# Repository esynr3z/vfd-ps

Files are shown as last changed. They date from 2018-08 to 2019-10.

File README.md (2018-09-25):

# Power supply for VFD

## Features

Main parts of the VFD power supply: inverting buck-boost converter on TPS54360 (supposed to use with ICs like PT6311 and etc) and filament driver on LM4871.

Inverting converter:

* Input voltage: 5V
* Output negative voltage: -15V to -30V
* Output current: 250mA @ 5V in

Filament driver:

* Input voltage: 5V
* Output voltage: 5 to 0 (dummy resistors to regulate)
* Output power: 2W @ 5V in

## Board

Schematic and pcb layout created in KiCad 6 Nightly Build (compatible with KiCad 5).

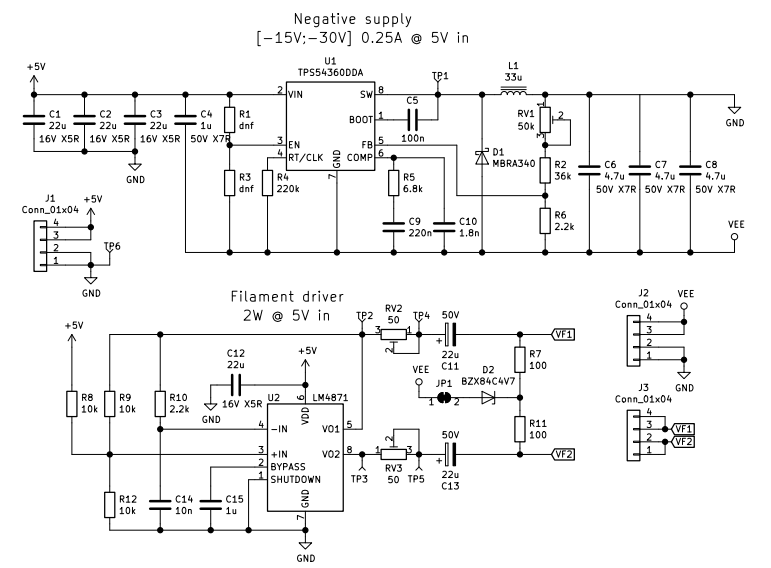
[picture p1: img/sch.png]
schematic

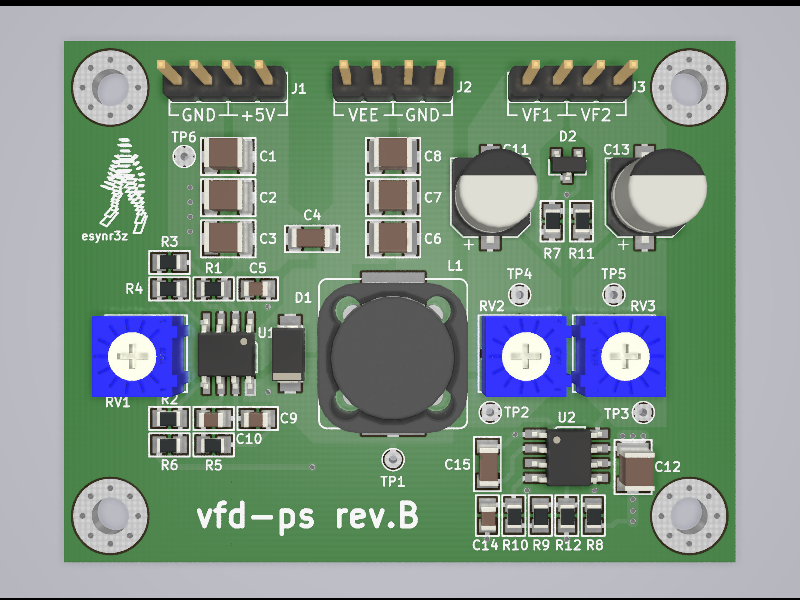
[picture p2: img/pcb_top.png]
pcb top

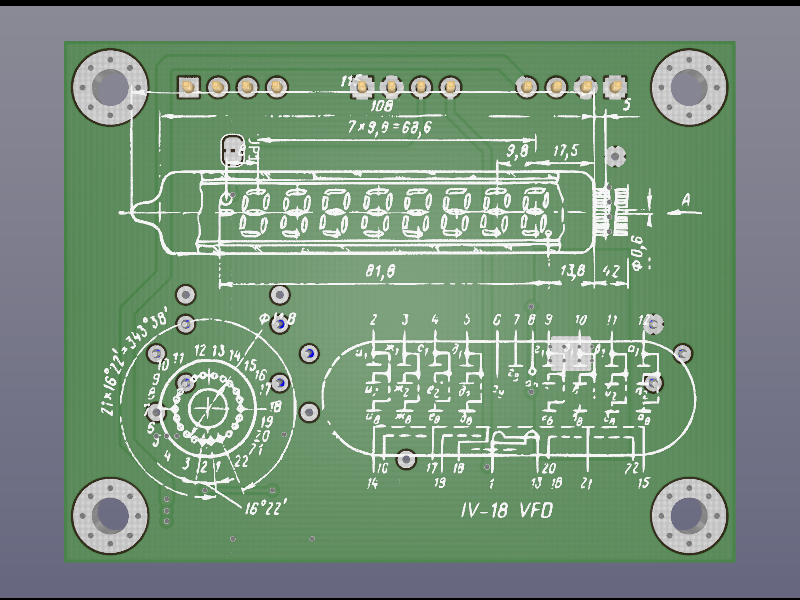
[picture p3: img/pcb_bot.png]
pcb bottom


## Notes

* ```misc``` folder contains some calculation and simulation sheets for several IC to get negative voltages

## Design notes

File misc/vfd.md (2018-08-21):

# VFD summary

Main specifications on some VFDs.

* **V_ag** - anodes and grids voltage
* **V_f** - filament voltage
* **I_at** - total current trough all anodes
* **I_g** - grid current
* **I_f** - filament current

| VFD | V_ag, V | I_at, mA | I_g, mA | V_f, V | I_f, mA |
|---:|---:|---:|---:|---:|---:|
| IV-3 | 20 | 0.3 | 3 | 0.8 | 50 |
| IV-3А | 20 | 0.3 | 3 | 0.8 | 30 |
| IV-4 | 25 | 0.45 | 6 | 2.6 | 50 |
| IV-6 | 25 | 0.6 | 10 | 1.0 | 50 |
| IV-8 | 20 | 0.8 | 3 | 0.8 | 50 |
| IV-11 | 25 | 3.5 | 12 | 1.5 | 100 |
| IV-12 | 25 | 3.5 | 12 | 1.5 | 100 |
| IV-17 | 25 | 2.7 | 6.5 | 2.5 | 47 |
| IV-18 | 50 | 45 | 10 | 5 | 85 |
| IV-21 | 27 | 0.7 | 7.0 | 1.0 | 100 |
| IV-22 | 27 | 12 | 0.02 | 2.4 | 35 |
|  IVL1-7/5 | 27 | 12 | 2.5 | 5 | 120 |
|  IVL2-7/5 | 24 | 27 | 3 | 2.4 | 58 |
|  IVC-4/7L | 27 | 70 | 10 | 2.4 | 100 |

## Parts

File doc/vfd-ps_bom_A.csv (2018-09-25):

Component | Description | Part | References | Value | Footprint | Quantity Per PCB | Datasheet | Rating
1 |  | Device_C | C10 | 1.8n | C_0805 | 1 | ~
2 |  | Device_C | C5 | 100n | C_0805 | 1 | ~
3 |  | Device_C | C14 | 10n | C_0805 | 1 | ~
4 |  | Device_C | C4 C15 | 1u | C_1206 | 2 | ~ | 50V X7R
5 |  | Device_C | C9 | 220n | C_0805 | 1 | ~
6 |  | Device_C | C1 C2 C3 C12 | 22u | C_1210 | 4 | ~ | 16V X5R
7 |  | Device_CP | C11 C13 | 22u | CP_Elec_6.3x7.7 | 2 | ~ | 50V
8 |  | Device_C | C6 C7 C8 | 4.7u | C_1210 | 3 | ~ | 50V X7R
9 |  | esynr3z_DiodeZener_BZX84C4V7 | D2 | BZX84C4V7 | SOT-23 | 1 | https://www.onsemi.com/pub/Collateral/BZX84C2V4LT1-D.PDF
10 |  | esynr3z_DiodeSchottky_MBRA340 | D1 | MBRA340 | SMA | 1 | https://www.onsemi.com/pub/Collateral/MBRA340T3-D.PDF
11 |  | Connector_Generic_Conn_01x04 | J1 J2 J3 | Conn_01x04 | PinHeader_1x04_P2.54mm_Vertical | 3 | ~
12 |  | Device_L_Core_Iron | L1 | 33u | Sumida_CDRH127 | 1 | ~
13 |  | Device_R | R7 R11 | 100 | R_0805 | 2 | ~
14 |  | Device_R | R8 R9 R12 | 10k | R_0805 | 3 | ~
15 |  | Device_R | R2 | 16k | R_0805 | 1 | ~
16 |  | Device_R | R6 | 1k | R_0805 | 1 | ~
17 |  | Device_R | R10 | 2.2k | R_0805 | 1 | ~
18 |  | Device_R | R4 | 220k | R_0805 | 1 | ~
19 |  | Device_R | R5 | 6.8k | R_0805 | 1 | ~
20 |  | Device_R_POT_TRIM | RV1 | 20k | Bourns_3362P | 1 | ~
21 |  | Device_R_POT_TRIM | RV2 RV3 | 50 | Bourns_3362P | 2 | ~
22 |  | esynr3z_AmplifierAudio_LM4871 | U2 | LM4871 | VSSOP-8_3.0x3.0mm_P0.65mm | 1 | http://www.ti.com/lit/ds/symlink/lm4871.pdf
23 |  | esynr3z_RegulatorSwitching_TPS54360DDA | U1 | TPS54360DDA | TI_SO-PowerPAD-8_ThermalVias | 1 | www.ti.com/lit/ds/symlink/tps54360.pdf
Component Groups: | 24
Component Count: | 38
Fitted Components: | 36
Number of PCBs: | 1
Total components: | 36
Schematic Version: | A
Schematic Date:
BoM Date: | Tue 25 Sep 2018 20:55:03 MSK
Schematic Source: | /home/esynr3z/MyRepos/vfd-ps/vfd-ps.sch
KiCad Version: | Eeschema 6.0.0-rc1-unknown-r13783-618182dc

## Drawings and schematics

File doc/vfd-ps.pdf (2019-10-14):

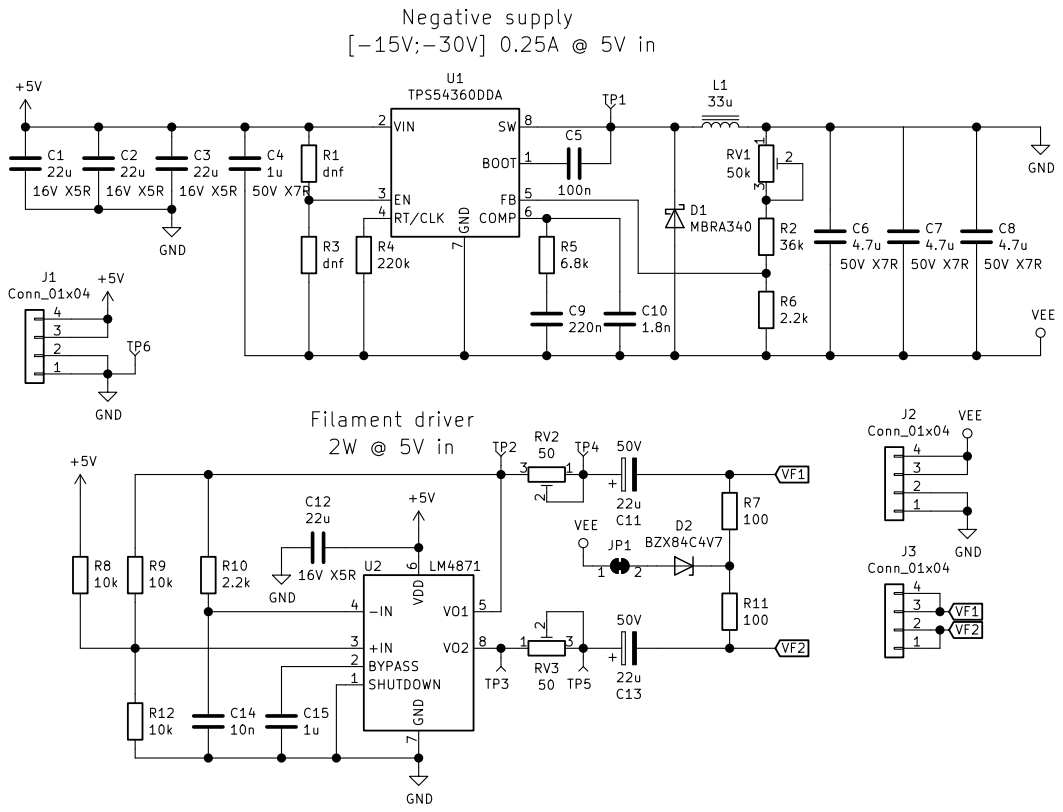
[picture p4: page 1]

File: vfd-ps.sch Sheet: /
Id: 1/1 Title: VFD power supply and filament driver

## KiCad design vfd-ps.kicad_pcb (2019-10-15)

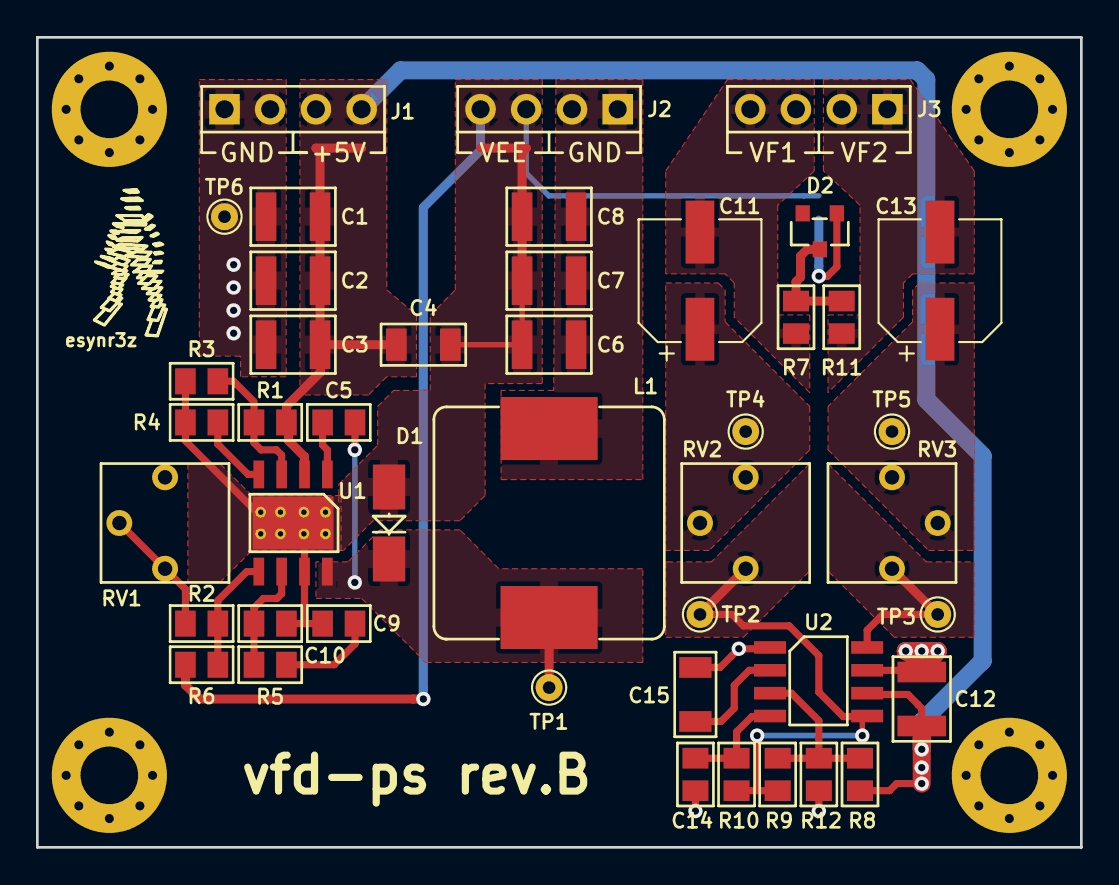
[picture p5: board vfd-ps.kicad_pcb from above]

Board: 2 copper layers, 58.0 x 45.0 mm, 45 parts (1 on the bottom side), 22 nets.

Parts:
C1, C2, C3, C12: 22u; C_1210
C4, C15: 1u; C_1206
C5: 100n; C_0805
C6, C7, C8: 4.7u; C_1210
C9: 220n; C_0805
C10: 1.8n; C_0805
C11, C13: 22u; CP_Elec_6.3x7.7
C14: 10n; C_0805
D1: MBRA340; SMA
D2: BZX84C4V7; SOT-23
J1, J2, J3: Conn_01x04; PinHeader_1x04_P2.54mm_Vertical
JP1: SolderJumper_2_Bridged; SolderJumper-2_P1.3mm_Bridged2Bar_RoundedPad1.0x1.5mm
L1: 33u; Sumida_CDRH127
R1, R3: dnf; R_0805
R2: 36k; R_0805
R4: 220k; R_0805
R5: 6.8k; R_0805
R6, R10: 2.2k; R_0805
R7, R11: 100; R_0805
R8, R9, R12: 10k; R_0805
RV1: 50k; Bourns_3362P
RV2, RV3: 50; Bourns_3362P
TP1, TP2, TP3, TP4, TP5, TP6: TestPoint; TestPoint_THTPad_D1.5mm_Drill0.7mm
U1: TPS54360DDA; TI_SO-PowerPAD-8_ThermalVias
U2: LM4871; SOIC-8_3.9x4.9mm_P1.27mm

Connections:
+5V: C1.1, C2.1, C3.1, C4.1, C12.1, J1.3, J1.4, R1.1, R8.2, U1.2, U2.6
GND: C1.2, C2.2, C3.2, C6.1, C7.1, C8.1, C12.2, C14.2, C15.2, J1.1, J1.2, J2.1, J2.2, L1.2, R12.2, RV1.1, TP6.1, U2.1, U2.7
GNDPAD: C4.2, C6.2, C7.2, C8.2, C9.2, C10.2, D1.2, J2.3, J2.4, JP1.1, R3.2, R4.2, R6.2, U1.7, U1.9
unnamed: C5.1, U1.1
unnamed: C5.2, D1.1, L1.1, TP1.1, U1.8
unnamed: C9.1, R5.2
unnamed: C10.1, R5.1, U1.6
unnamed: C11.1, RV2.1, RV2.2, TP4.1
unnamed: C13.1, RV3.2, RV3.3, TP5.1
unnamed: C14.1, R10.1, U2.4
unnamed: C15.1, U2.2
unnamed: D2.1, JP1.2
unnamed: D2.3, R7.2, R11.1
unnamed: R1.2, R3.1, U1.3
unnamed: R2.1, RV1.2, RV1.3
unnamed: R2.2, R6.1, U1.5
unnamed: R4.1, U1.4
unnamed: R9.2, R10.2, RV2.3, TP2.1, U2.5
unnamed: R8.1, R9.1, R12.1, U2.3
unnamed: RV3.1, TP3.1, U2.8
VF1: C11.2, J3.3, J3.4, R7.1
VF2: C13.2, J3.1, J3.2, R11.2

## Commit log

2018-08-11 Add filament driver on ad8534
2018-08-11 ad8534-filament: add series resistor for setting up current
2018-08-11 ad8534-filament: rename voltage sources
2018-08-11 Add ncp3163 calculation worksheet
    [NCP3163 DWS.xls]
2018-08-11 Add zener to bias filament
2018-08-12 ad8534-filament: fix component nominals
2018-08-24 Add filament driver model on lm4871
2018-08-26 Rename dir with sim models, calculations and other info
    [NCP3163 DWS.xls]
2018-08-26 Add kicad project
    [filament.sch, negative.sch, vfd-ps.kicad_pcb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]
2018-08-30 Draw first schematic
    [NCP3163 DWS.xls, filament.sch, negative.sch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]
2018-09-16 Add LM2576 inverting buck-boost simulation
2018-09-17 Add TPS54360 inverting buck-boost smath calculations
2018-09-18 Replace NCP3163 converter with TPS54360
    [vfd-ps.sch]
2018-09-19 Schematic update: footprints, nominals, testpoints, etc
    [vfd-ps.sch]
2018-09-19 Minor tweaks in schematic
    [vfd-ps.sch]
2018-09-19 Place all components on pcb
    [vfd-ps.kicad_pcb]
2018-09-19 Place all references on silk layer
    [vfd-ps.kicad_pcb]
2018-09-20 Minor components placement tweaks
    [vfd-ps.kicad_pcb]
2018-09-20 Replace connectors, add testpoints, pcb rotate and align
    [vfd-ps.kicad_pcb, vfd-ps.sch]
2018-09-20 Trace buck-boost pcb part
    [vfd-ps.kicad_pcb]
2018-09-20 Trace all pcb nets
    [vfd-ps.kicad_pcb, vfd-ps.sch]
2018-09-21 Add image to silk
    [vfd-ps.kicad_pcb]
2018-09-21 Some minor silk fixes
    [vfd-ps.kicad_pcb]
2018-09-22 Make project portable
    [Bourns_3362P.step, CP_Elec_6.3x7.7.step, Sumida_CDRH127.step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]
2018-09-25 Update revision numbering
    [vfd-ps.kicad_pcb, vfd-ps.sch, vfd-ps_bom_A.csv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]
2018-09-26 Add gerbers
    [vfd-ps-B.Cu.gbr, vfd-ps-B.Mask.gbr, vfd-ps-B.SilkS.gbr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]
2019-10-08 Align fab layer labels
    [vfd-ps.kicad_pcb]
2019-10-08 Fix wrong cap polarity in fillament scheme
    [vfd-ps.kicad_pcb, vfd-ps.sch]
2019-10-08 Add fixed gerbers
    [vfd-ps-B.Cu.gbr, vfd-ps-B.Mask.gbr, vfd-ps-B.SilkS.gbr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]
2019-10-13 Remove all local libs and switch to submodule library
    [Bourns_3362P.step, CP_Elec_6.3x7.7.step, Sumida_CDRH127.step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]
2019-10-13 Replace lm4871 footprint
    [vfd-ps.kicad_pcb, vfd-ps.sch]
2019-10-13 Align labels on silk and fab layers
    [vfd-ps.kicad_pcb, vfd-ps.sch]
2019-10-14 Revision B
    [vfd-ps-B.Cu.gbr, vfd-ps-B.Mask.gbr, vfd-ps-B.SilkS.gbr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]
2019-10-15 Fix zener pinout
    [vfd-ps.kicad_pcb]
